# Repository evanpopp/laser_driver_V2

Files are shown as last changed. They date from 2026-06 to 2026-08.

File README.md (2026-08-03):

# Custom Laser Assembly V2

Welcome to the repository for my custom laser assembly V2, which is a more compact and tunable version of my V1 laser assembly. This particular project is designed for the NUBB23 laser diode array (22W). Some major differences compared to the first version are an integrated auto-focusing system, a more compact and sturdy construction, a cheaper and more manufacturable heatsink assembly, and better focusing ability. 

This is currently still a work in progress, and I plan to design a new laser driver with an integrated MCU, TEC driver, servo driver, and supercapacitors (for pulsed operation). 

---

## 📸 Project Gallery

Here are some renders of the custom PCB and the mechanical assemblies:

### Optical Assembly Renders
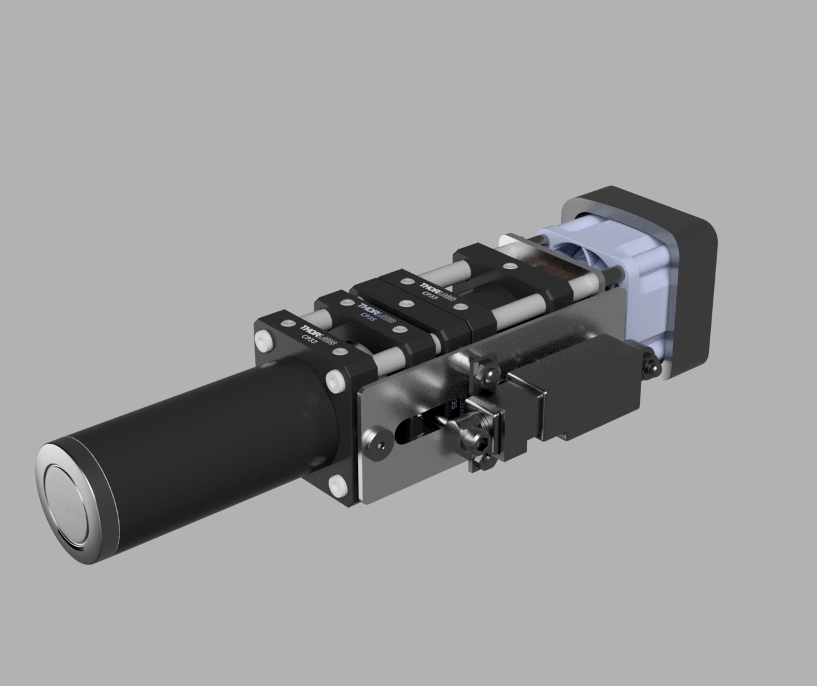
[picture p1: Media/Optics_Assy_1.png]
Optics Assy Angled View

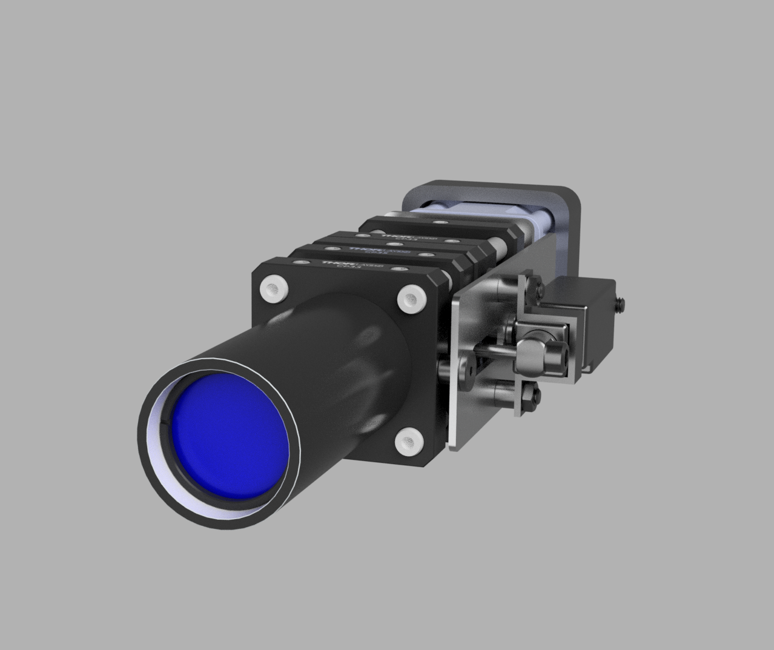
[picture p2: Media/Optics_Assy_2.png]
Optics Assy Front View


### Laser Assembly Render
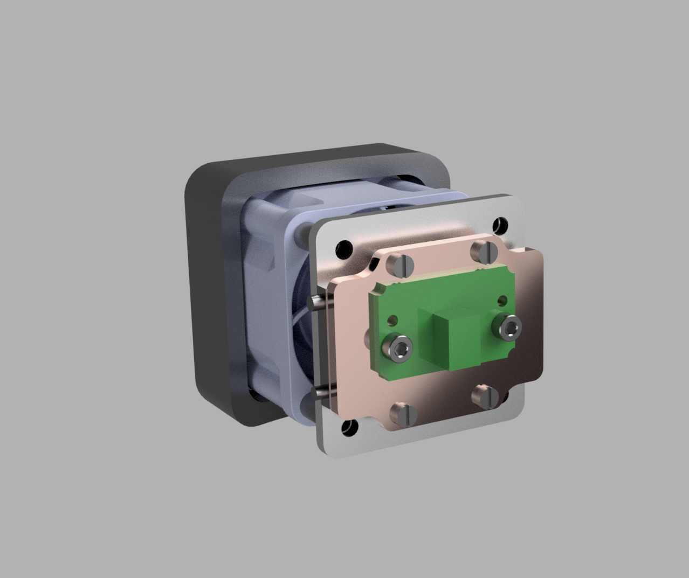
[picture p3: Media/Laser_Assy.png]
Laser Assy


### Optical Assembly Real Image (No Servo)
Real Assy

---

## ✨ Features

* **Active Cooling:** With the custom heatsink, mount, fan, and TEC assembled, you should have more than enough cooling for 22W lasers. 
* **Optical Integration:** I am using the Thorlabs 30mm cage system with lenses to better focus the beam. Now, the entire cage/laser system is one piece, which means this laser assembly can be integrated into a larger system. Improvements can most likely be made to my setup, as lens system design is not my specialty.
* **Integrated Focusing:** With the servo connected, you can now fine-tune the laser focal point. Further electronic integration will be implemented for digital control, possibly allowing auto-focusing with a separate range-finding component.

---

## 📂 Repository Structure

* `/Lens_Assy` - Contains the CAD files (STEP) for the custom mechanical mounts, plastic enclosure, and the BOM.
* `/Media` - Contains various images and videos of the laser assembly.

---

## 🛠️ Hardware Specifications

### Mechanical Mount
* **Cage Compatibility:** Thorlabs 30mm Cage System
* **Cooling Method:** Active (Heatsink + Fan + TEC)
* **Linear Servo:** Actuonix L12 10mm
* **Material:** Copper laser mount, aluminum heatsink, 3D printed plastic

---

## 🚀 Assembly Instructions

1. **Optics Assy:** More detailed instructions will be available at a later point; refer to the provided STEP assembly file in the interim.

---

## 🥽 Operating Instructions

1. **Safety:** More detailed instructions will be available when the electronics are designed, tested, and published. Always wear proper safety goggles when working with lasers. 

---

## ⚠️ Safety Warning

**WARNING: LASER RADIATION**

This project involves the operation of lasers that can cause immediate and permanent damage to eyesight, skin, and materials. 
* Always wear appropriate Laser Safety Goggles rated for the specific wavelength and optical density (OD) of your laser diode.
* Never look directly into the beam or any specular reflections.
* This hardware is provided "as-is" for educational and hobbyist purposes. You are solely responsible for ensuring you operate your laser equipment safely and in accordance with local regulations.

---

## 📝 License

This project is licensed under the [MIT License](License.txt) - see the LICENSE file for details.

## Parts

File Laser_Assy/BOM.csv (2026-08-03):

Quantity | Description | MPN | Manufacturer
1 | Custom heatsink | NUBB23 HTSK
1 | Custom Laser mount | NUBB23 Mount
1 | Custom servo mount | Servo Mount
1 | Custom Fan Cover | Fan Cover
1 | Nichia NUBB23 455nm 22000mW Blue Laser Diode | NUBB23 | Nichia
1 | 40 x 20 x 3.0 mm, 11.0 A Input with Leads, Peltier (TEC) Module | CP1140203 | same sky
1 | L12 Micro Linear Actuator | L12-10-xxx-xx-x | actuonix
1 | Heatsink | ATS-FPX-73-CX-R0 | QATS
1 | Fan | 9HVA0312P3XXXX | Sanyo Denki
1 | Snap-On Plastic Dust Cap for SM1 Lens Tubes, 5 Pack | SM1EC2B | Thorlabs
1 | SM1 Lens Tube, 2.50" Thread Depth, One Retaining Ring Included | SM1L25 | Thorlabs
2 | SM1-Threaded 30 mm Cage Plate, 0.35" Thick, 2 Retaining Rings, 8-32 Tap | CP33 | Thorlabs
3 | 30 mm Cage Plate with Ø1" Double Bore, 8-32 Tap | cp35 | Thorlabs
1 | SM1 Lens Tube, 1.00" Thread Depth, One Retaining Ring Included | SM1L10 | Thorlabs
1 | Cage Assembly Rod, 1/2" Long, Ø6 mm, 4 Pack | ER05-P4 | Thorlabs
1 | Cage Assembly Rod, 3" Long, Ø6 mm, 4 Pack | ER3-P4 | Thorlabs
1 | Ø1" Brass Optic Spacer, 5 mm in Length | SM1S5M | Thorlabs
2 | Ø1" Brass Optic Spacer, 1 mm in Length | SM1S1M | Thorlabs
2 | Ø1" N-BK7 Negative Meniscus Lens, f = -100 mm, Uncoated | LF1822 | Thorlabs
1 | N-BK7 Plano-Concave Lens, Ø1", f = -50 mm, Uncoated | LC1715 | Thorlabs
1 | N-BK7 Plano-Convex Lens, Ø1", f = 200 mm, Uncoated | LA1708 | Thorlabs
1 | Ø1" N-BK7 Positive Meniscus Lens, f = 200 mm, Uncoated | LE1202 | Thorlabs
1 | N-BK7 Best Form Lens, Ø1", f = 200 mm, Uncoated | LBF254-200 | Thorlabs
3 | SM1 Retaining Ring for Ø1" Lens Tubes and Mounts | SM1RR | Thorlabs
2 | socket head screws, hex drive, 5/16" long | 91223a318 | McMaster-Carr
2 | socket head screws, hex drive, 3/8" long | 91223a319 | McMaster-Carr
1 | socket head captive panel screws, 0.266" diameter head | 95966a339 | McMaster-Carr
1 | socket head screws, hex drive, 3/4" long | 91223a323 | McMaster-Carr
2 | spacers, 1/4" od | 92510a461 | McMaster-Carr
2 | spacers, 1/4" od | 92510a460 | McMaster-Carr
1 | spacers, 1/4" od | 92510a462 | McMaster-Carr
3 | hex nuts, narrow profile, 8-32 threads | 90760a009 | McMaster-Carr
4 | spacers, unthreaded hole mount, 7/16" long | 92510a698 | McMaster-Carr
4 | socket head screws, hex drive, 1 3/4" long | 91251a160 | McMaster-Carr
4 | rounded head screws, black plastic | 96295a104 | McMaster-Carr
2 | socket head screws, m2.5 x 0.45 mm thread size | 91290a051 | McMaster-Carr

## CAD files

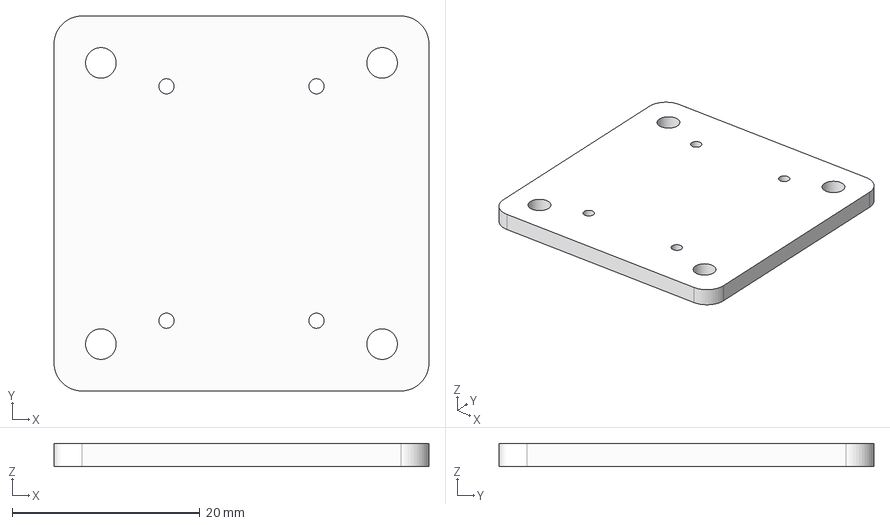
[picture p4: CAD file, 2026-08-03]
Laser_Assy/Metal/Heatsink.step
40.0 x 40.0 x 2.50 mm

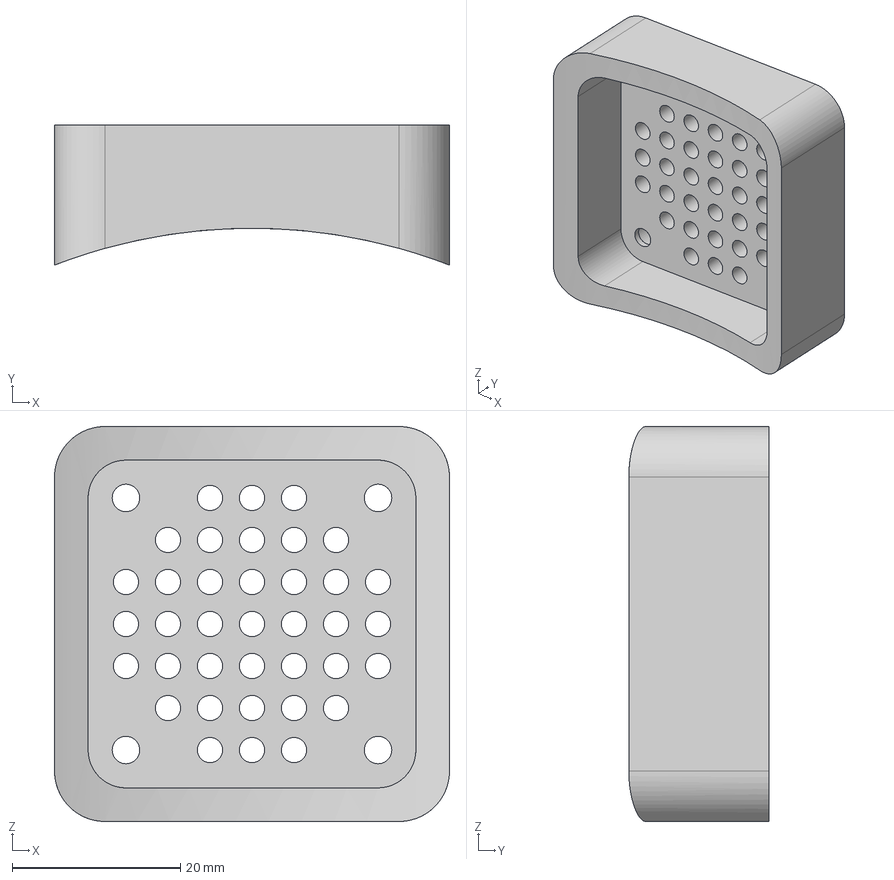
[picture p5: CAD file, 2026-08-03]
Laser_Assy/Plastic/Fan_Cover.step
47.0 x 16.7 x 47.0 mm

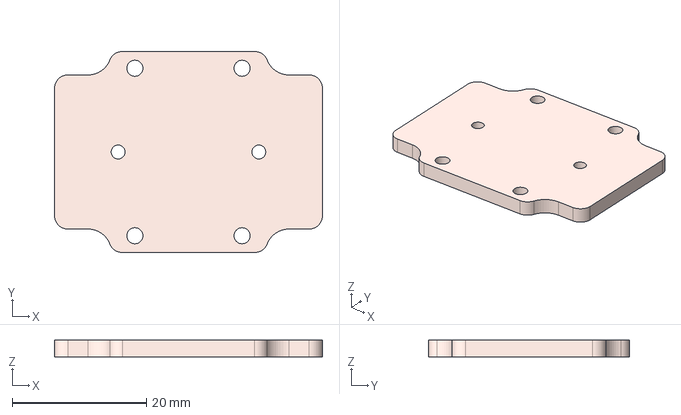
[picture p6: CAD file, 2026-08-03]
Laser_Assy/Metal/Laser_Mount.step
40.0 x 30.0 x 2.50 mm

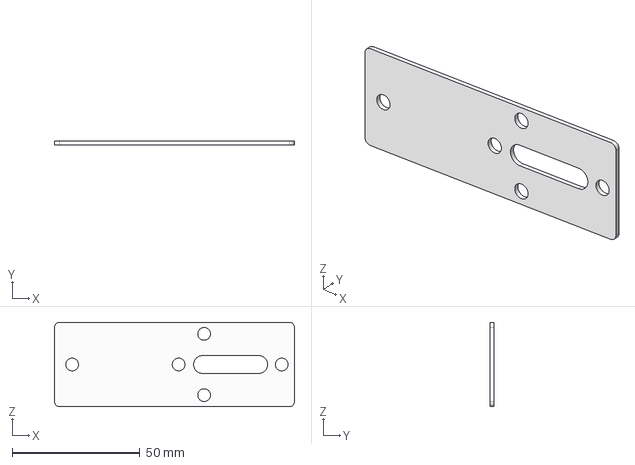
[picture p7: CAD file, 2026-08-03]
Laser_Assy/Metal/Servo_Mount.step
94.0 x 1.50 x 33.0 mm

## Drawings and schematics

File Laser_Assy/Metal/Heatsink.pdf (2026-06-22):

30 | 5 | 02.5 | 27.5 | 30 40
40 | 2.5 TYP R3 ⁴x Ø3.26 | 4x M2x0.4 6H

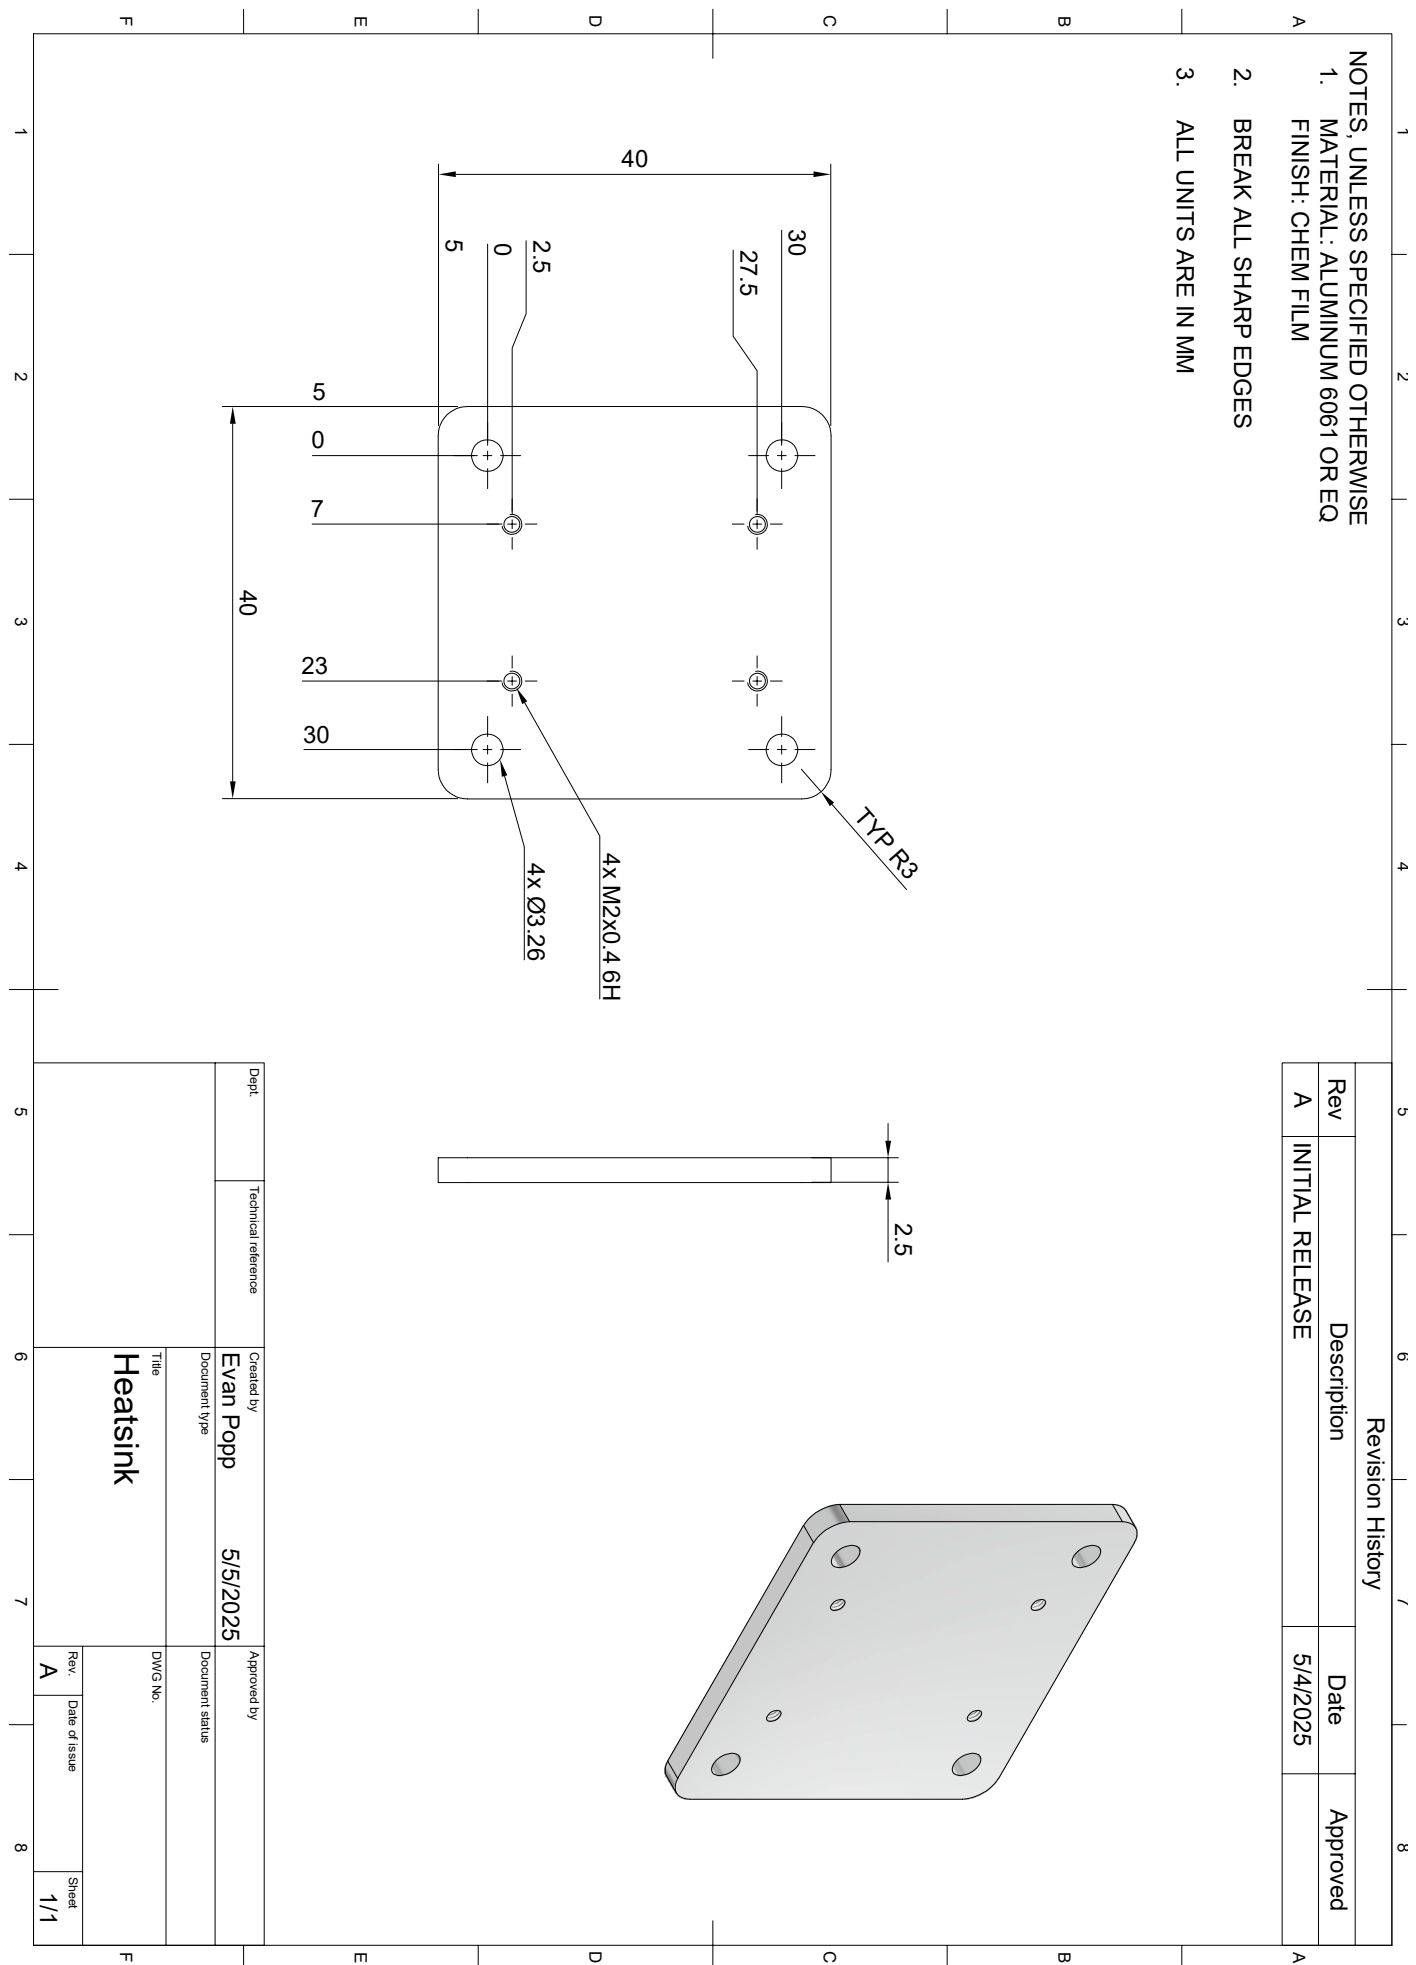
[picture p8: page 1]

1 A 2 3 4 5 6 7 8 1 2 3 4 5 6 7 8 FEDCB FEDCBA Dept. Technical reference Created by Approved by Title DWG No. Document type Document status Rev. Date of issue Sheet A 5/5/2025 1/1 Heatsink Evan Popp NOTES, UNLESS SPECIFIED OTHERWISE 1. MATERIAL: ALUMINUM 6061 OR EQ FINISH: CHEM FILM 3. ALL UNITS ARE IN MM 2. BREAK ALL SHARP EDGES Revision History Rev Description Date Approved A INITIAL RELEASE 5/4/2025 057

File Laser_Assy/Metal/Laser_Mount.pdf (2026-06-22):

9.5

21 | 01512.5 | 12.5 30

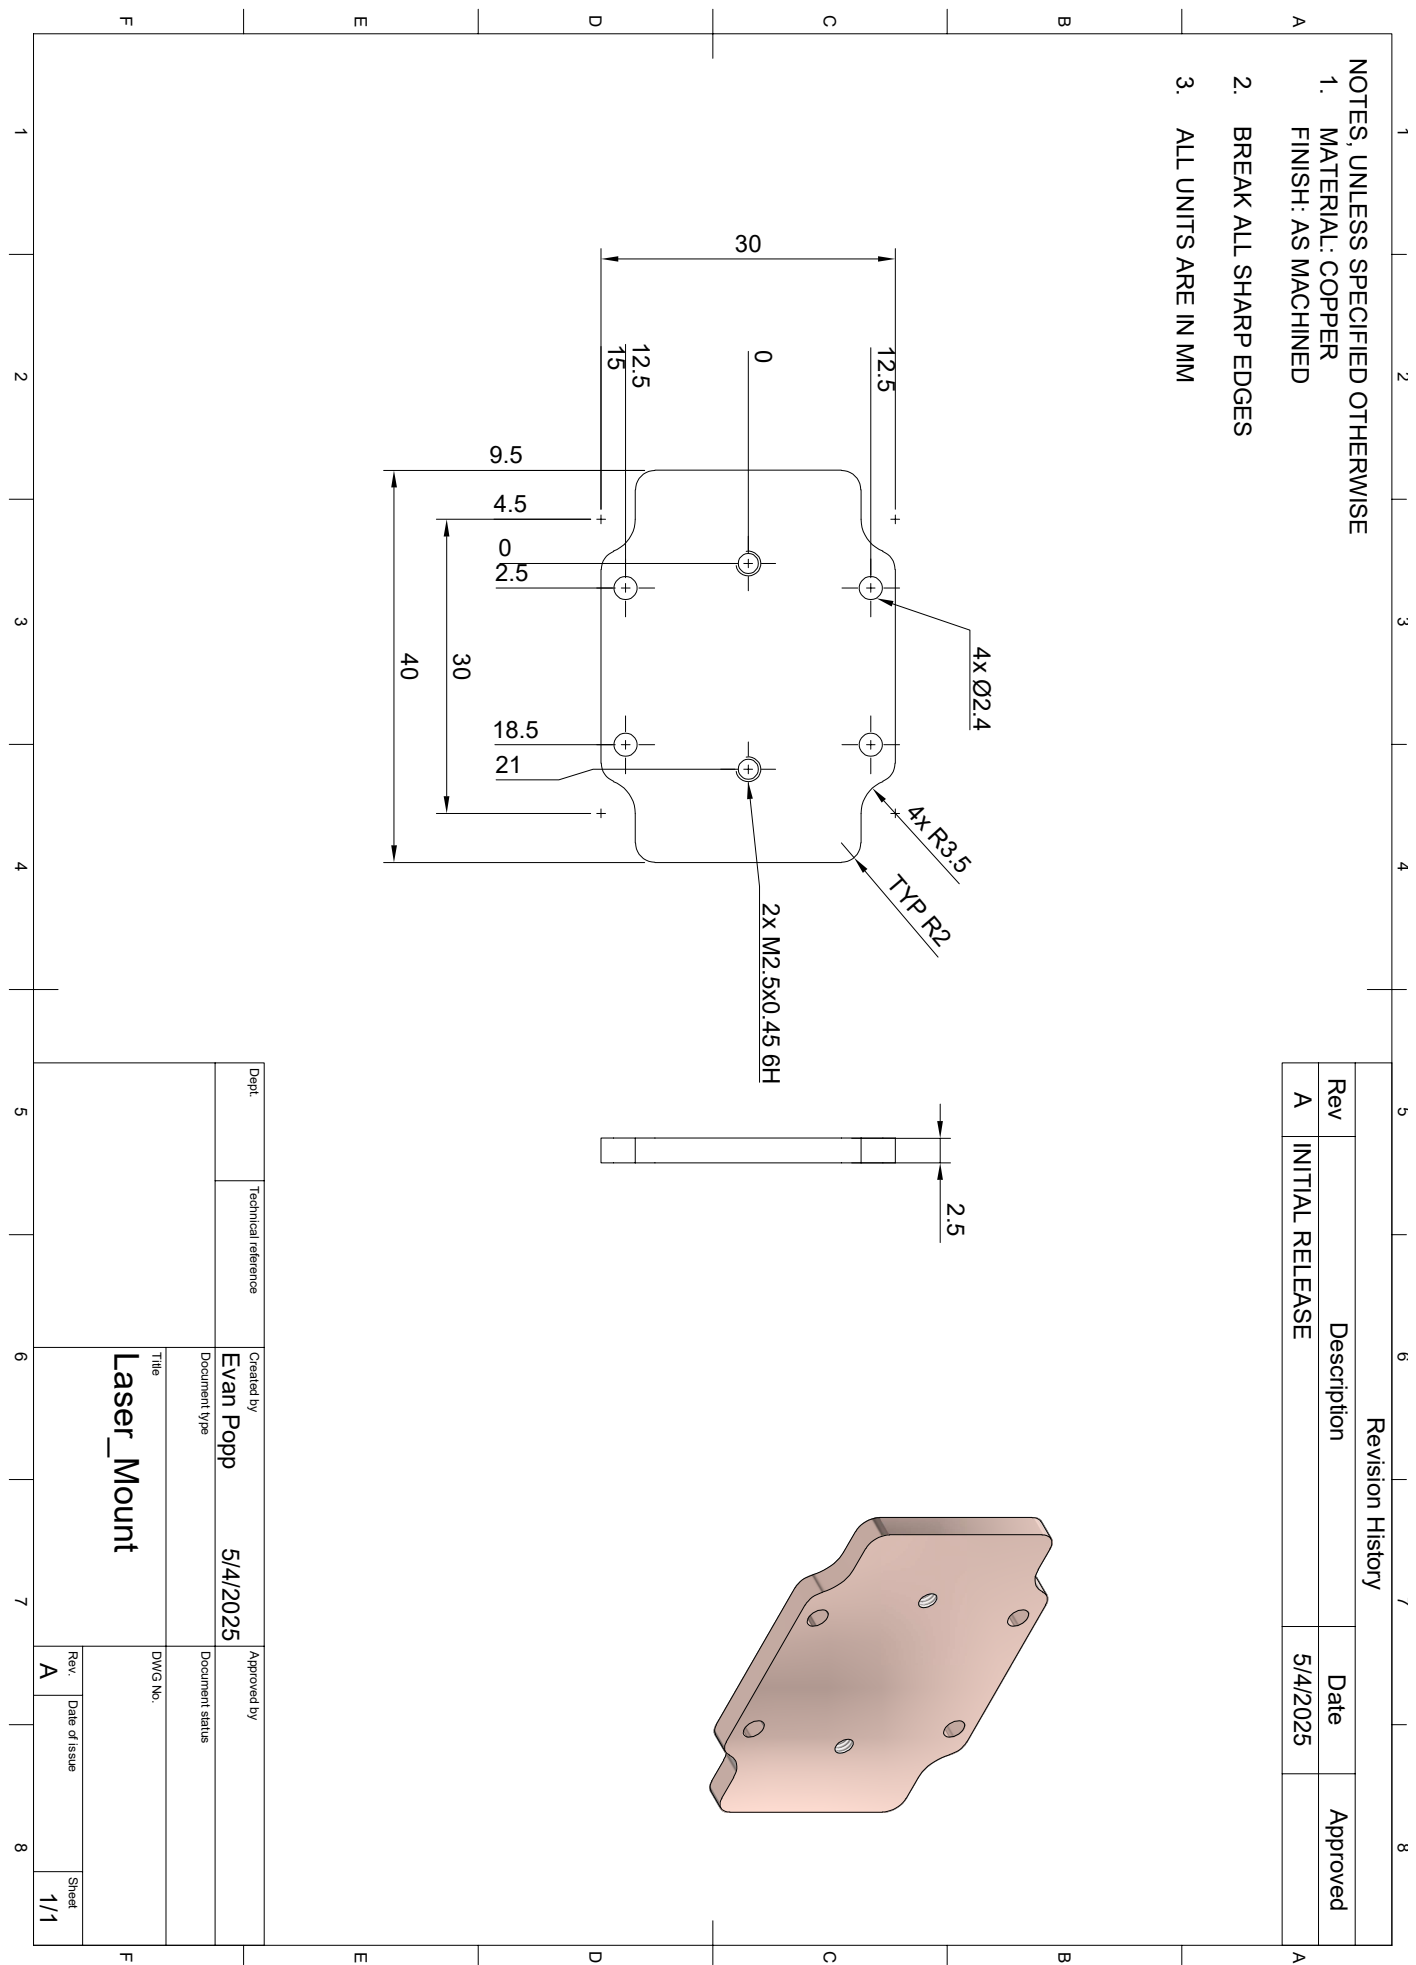
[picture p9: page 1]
4x R3.5 TYP R2 2.5; NOTES, UNLESS SPECIFIED OTHERWISE ¹. MATERIAL: COPPER FINISH: AS MACHINED ³. ALL UNITS ARE IN MM; 2. BREAK ALL SHARP EDGES 4x Ø2.4 2x M2.5x0.45 6H

1 A 2 3 4 5 6 7 8 1 2 3 4 5 6 7 8 FEDCB FEDCBA Dept. Technical reference Created by Approved by Title DWG No. Document type Document status Rev. Date of issue Sheet A 5/4/2025 1/1 Laser_Mount Evan Popp Revision History Rev Description Date Approved A INITIAL RELEASE 5/4/2025 0

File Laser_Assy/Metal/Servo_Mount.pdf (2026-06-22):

6.9

51.1 ⁰¹² ¹⁶.5 | 12

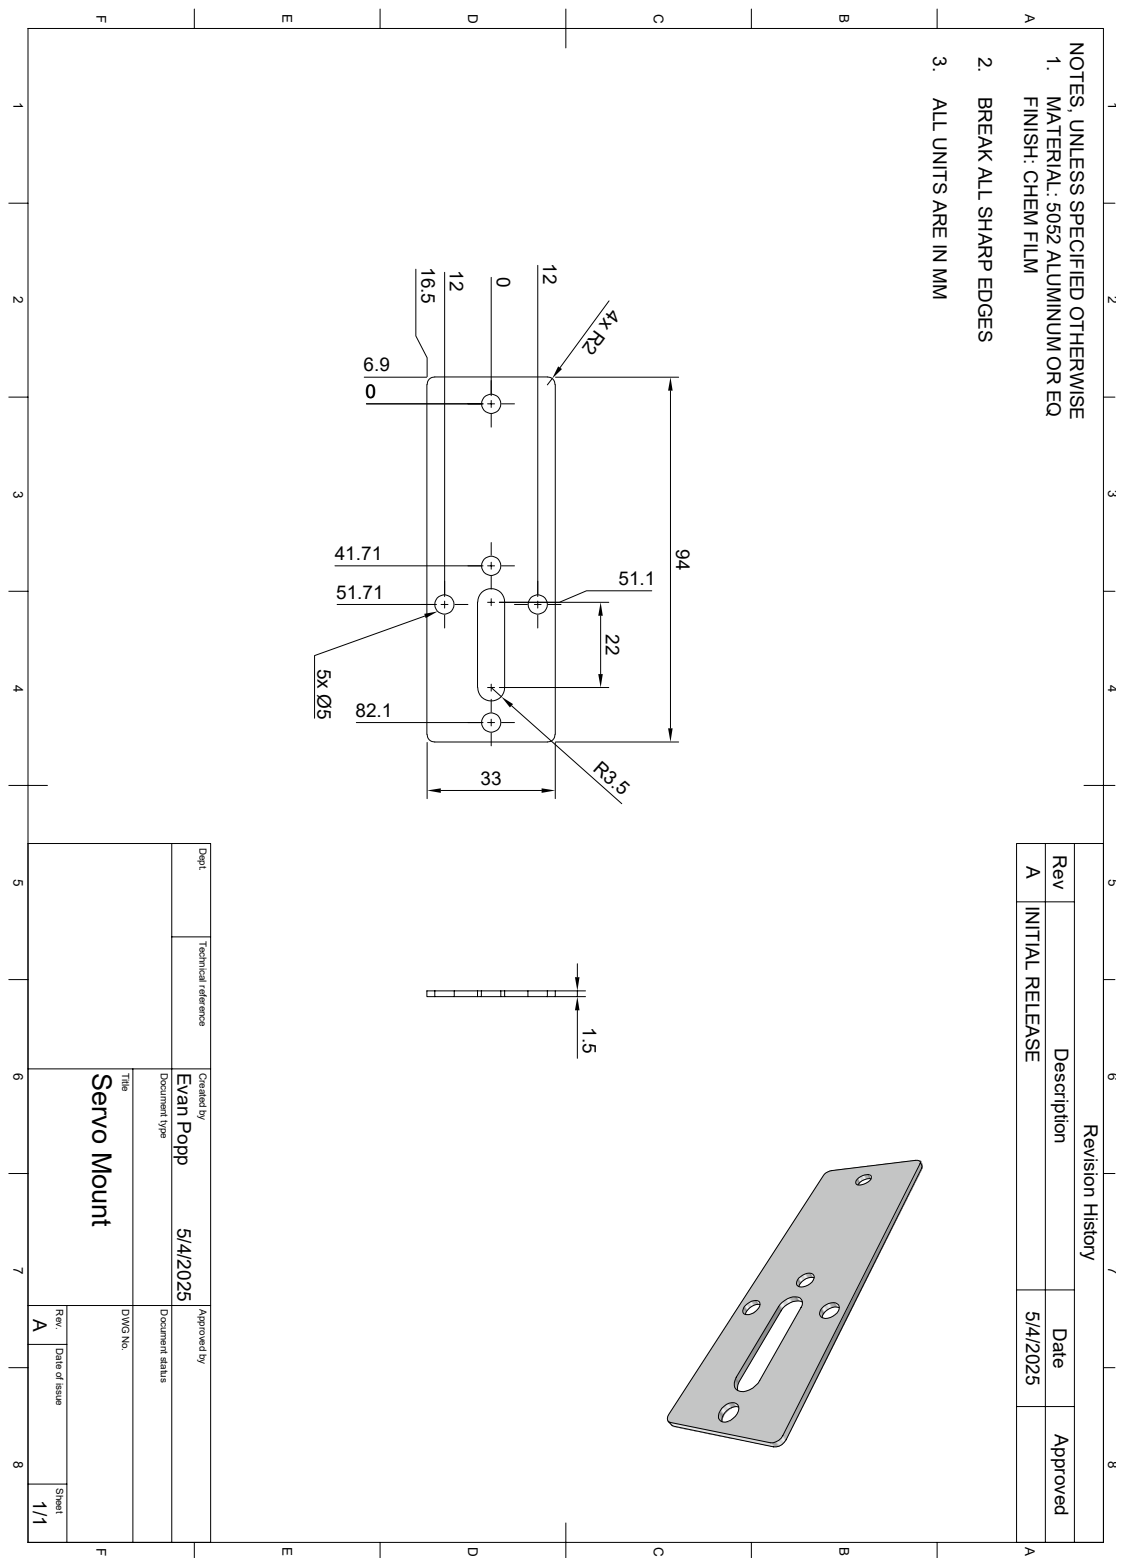
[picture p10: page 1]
Revision History Rev Description Date Approved A INITIAL RELEASE 5/4/2025

1 A 2 3 4 5 6 7 8 1 2 3 4 5 6 7 8 FEDCB FEDCBA Dept. Technical reference Created by Approved by Title DWG No. Document type Document status Rev. Date of issue Sheet A 5/4/2025 1/1 Servo Mount Evan Popp NOTES, UNLESS SPECIFIED OTHERWISE 1. MATERIAL: 5052 ALUMINUM OR EQ FINISH: CHEM FILM 3. ALL UNITS ARE IN MM 2. BREAK ALL SHARP EDGES 0

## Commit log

2026-06-22 init upload
    [Heatsink.step, Laser_Mount.step, Servo_Mount.step]
2026-06-22 Add initial README for laser driver project
2026-08-03 Released proper documentation and files
    [BOM.csv, Fan_Cover.step, Heatsink.step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]
